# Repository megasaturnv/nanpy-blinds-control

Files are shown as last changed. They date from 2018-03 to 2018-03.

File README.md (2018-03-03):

# nanpy-blinds-control
Python program which performs actions depending on sunset and sunrise times

It controls an Arduino via the serial port with Nanpy: https://github.com/nanpy/nanpy

KiCad circuit board schematics are available in /blindsControlKiCad/





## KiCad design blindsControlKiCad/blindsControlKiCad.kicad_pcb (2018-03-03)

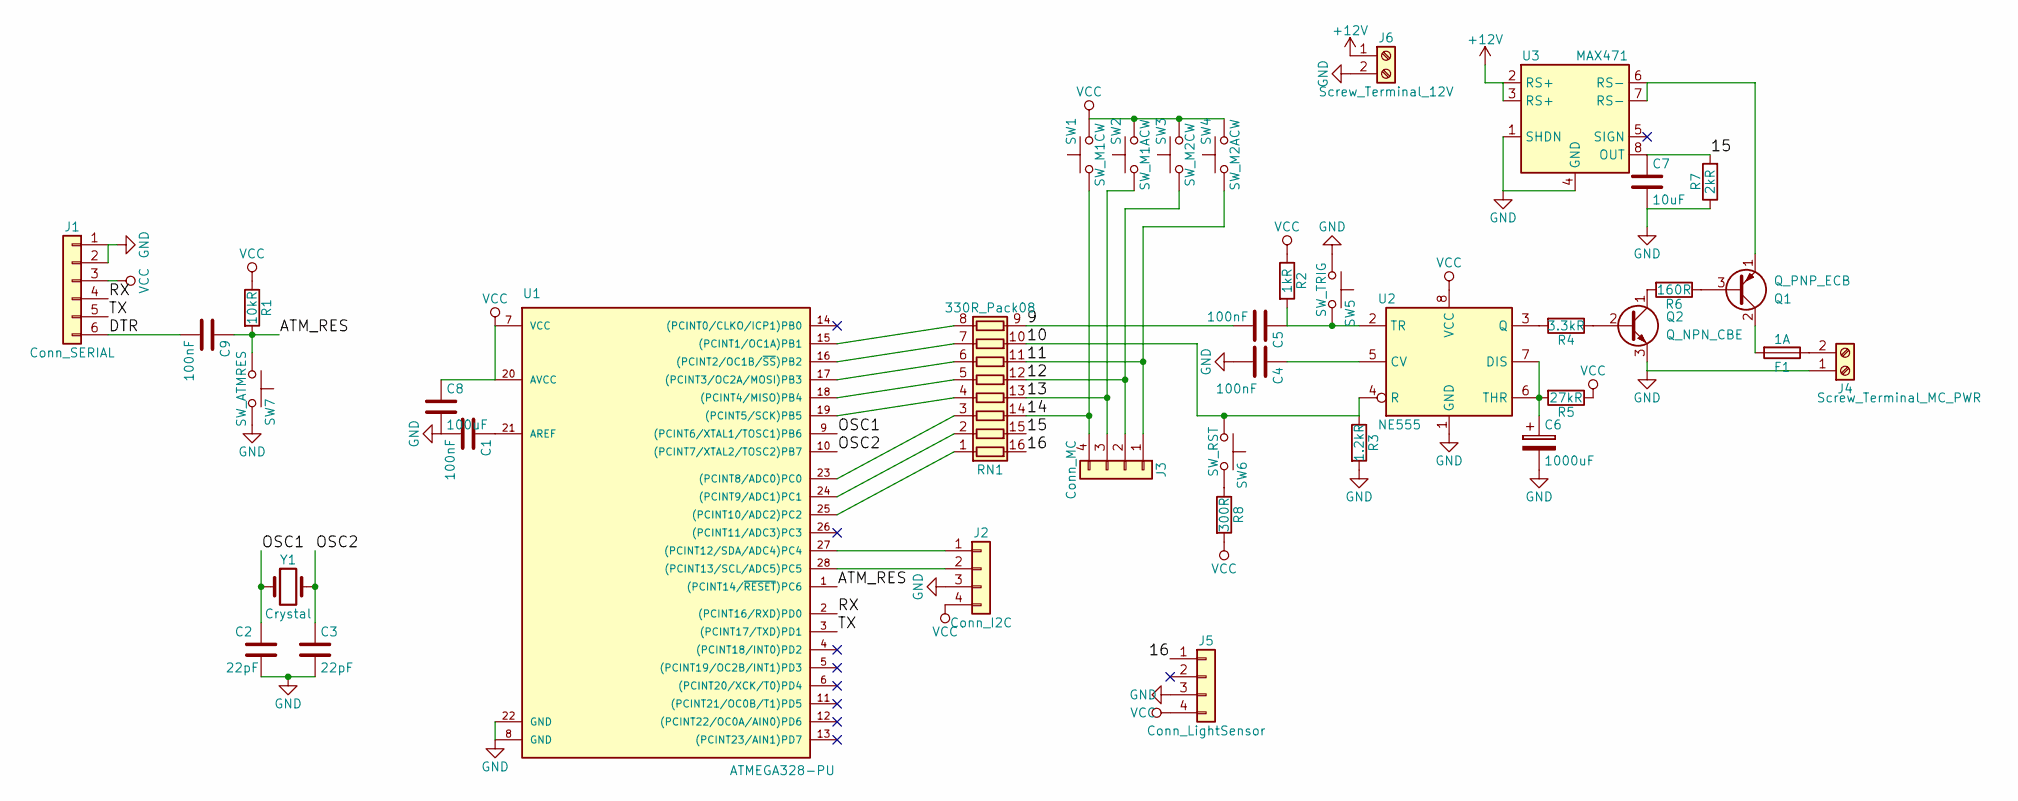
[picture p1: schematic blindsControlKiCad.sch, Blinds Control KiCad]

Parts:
C1, C4: 100nF; C_Disc_D3.0mm_W1.6mm_P2.50mm
C2, C3: 22pF; C_Disc_D3.0mm_W1.6mm_P2.50mm
C5, C9: 100nF; C_Disc_D4.3mm_W1.9mm_P5.00mm
C6: 1000uF; CP_Radial_D10.0mm_P5.00mm
C7: 10uF; CP_Radial_D5.0mm_P2.50mm
C8: 100uF; CP_Radial_D5.0mm_P2.50mm
F1: 1A; Fuseholder5x20_horiz_open_inline_Type-I
J1: Conn_SERIAL; Pin_Header_Angled_1x06_Pitch2.54mm
J2: Conn_I2C; Pin_Header_Straight_1x04_Pitch2.54mm
J3: Conn_MC; Pin_Header_Straight_1x04_Pitch2.54mm
J4: Screw_Terminal_MC_PWR; TerminalBlock_Phoenix_MKDS1.5-2pol
J5: Conn_LightSensor; Pin_Header_Straight_1x04_Pitch2.54mm
J6: Screw_Terminal_12V; TerminalBlock_Phoenix_MKDS1.5-2pol
Q1: Q_PNP_ECB; TO-126_Vertical
Q2: Q_NPN_CBE; TO-92_Inline_Wide
R1: 10kR; R_Axial_DIN0204_L3.6mm_D1.6mm_P5.08mm_Horizontal
R2: 1kR; R_Axial_DIN0207_L6.3mm_D2.5mm_P10.16mm_Horizontal
R3: 1.2kR; R_Axial_DIN0207_L6.3mm_D2.5mm_P10.16mm_Horizontal
R4: 3.3kR; R_Axial_DIN0207_L6.3mm_D2.5mm_P10.16mm_Horizontal
R5: 27kR; R_Axial_DIN0207_L6.3mm_D2.5mm_P15.24mm_Horizontal
R6: 160R; R_Axial_DIN0207_L6.3mm_D2.5mm_P10.16mm_Horizontal
R7: 2kR; R_Axial_DIN0309_L9.0mm_D3.2mm_P12.70mm_Horizontal
R8: 300R; R_Axial_DIN0309_L9.0mm_D3.2mm_P12.70mm_Horizontal
RN1: 330R_Pack08; DIP-16_W7.62mm
SW1: SW_M1CW; SW_Tactile_Straight_KSA0Axx1LFTR
SW2: SW_M1ACW; SW_Tactile_Straight_KSA0Axx1LFTR
SW3: SW_M2CW; SW_Tactile_Straight_KSA0Axx1LFTR
SW4: SW_M2ACW; SW_Tactile_Straight_KSA0Axx1LFTR
SW5: SW_TRIG; SW_Tactile_Straight_KSA0Axx1LFTR
SW6: SW_RST; SW_Tactile_Straight_KSA0Axx1LFTR
SW7: SW_ATMRES; SW_Tactile_Straight_KSA0Axx1LFTR
U1: ATMEGA328-PU; DIP-28_W7.62mm
U2: NE555; DIP-8_W7.62mm
U3: MAX471; DIP-8_W7.62mm
Y1: Crystal; Crystal_HC49-4H_Vertical

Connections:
+12V: J6.1, U3.2 (RS+), U3.3 (RS+)
/9: C5.2, RN1.9 (R8.2)
/10: R3.1, RN1.10 (R7.2), SW6.1, U2.4 (R)
/11: J3.1, RN1.11 (R6.2), SW4.1
/12: J3.2, RN1.12 (R5.2), SW3.1
/13: J3.3, RN1.13 (R4.2), SW2.1
/14: J3.4, RN1.14 (R3.2), SW1.1
/15: C7.1, R7.2, RN1.15 (R2.2), U3.8 (OUT)
/16: J5.1, RN1.16 (R1.2)
/ATM_RES: C9.1, R1.2, SW7.1, U1.1 ((PCINT14/~RESET~)PC6)
/DTR: C9.2, J1.6
/OSC1: C2.1, U1.9 ((PCINT6/XTAL1/TOSC1)PB6), Y1.1
/OSC2: C3.1, U1.10 ((PCINT7/XTAL2/TOSC2)PB7), Y1.2
/RX: J1.4, U1.2 ((PCINT16/RXD)PD0)
/TX: J1.5, U1.3 ((PCINT17/TXD)PD1)
GND: C1.2, C2.2, C3.2, C4.2, C6.2, C7.2, C8.2, J1.1, J1.2, J2.3, J4.1, J5.3, J6.2, Q2.3 (E), R3.2, R7.1, SW5.1, SW7.2, U1.8 (GND), U1.22 (GND), U2.1 (GND), U3.1 (SHDN), U3.4 (GND)
unnamed: C1.1, U1.21 (AREF)
unnamed: C4.1, U2.5 (CV)
unnamed: C5.1, R2.2, SW5.2, U2.2 (TR)
unnamed: C6.1, R5.2, U2.6 (THR), U2.7 (DIS)
unnamed: F1.1, J4.2
unnamed: F1.2, Q1.2 (C)
unnamed: J2.1, U1.27 ((PCINT12/SDA/ADC4)PC4)
unnamed: J2.2, U1.28 ((PCINT13/SCL/ADC5)PC5)
unnamed: Q1.1 (E), U3.6 (RS-), U3.7 (RS-)
unnamed: Q1.3 (B), R6.1
unnamed: Q2.1 (C), R6.2
unnamed: Q2.2 (B), R4.1
unnamed: R4.2, U2.3 (Q)
unnamed: R8.1, SW6.2
unnamed: RN1.1 (R1.1), U1.25 ((PCINT10/ADC2)PC2)
unnamed: RN1.2 (R2.1), U1.24 ((PCINT9/ADC1)PC1)
unnamed: RN1.3 (R3.1), U1.23 ((PCINT8/ADC0)PC0)
unnamed: RN1.4 (R4.1), U1.19 ((PCINT5/SCK)PB5)
unnamed: RN1.5 (R5.1), U1.18 ((PCINT4/MISO)PB4)
unnamed: RN1.6 (R6.1), U1.17 ((PCINT3/OC2A/MOSI)PB3)
unnamed: RN1.7 (R7.1), U1.16 ((PCINT2/OC1B/~SS~)PB2)
unnamed: RN1.8 (R8.1), U1.15 ((PCINT1/OC1A)PB1)
VCC: C8.1, J1.3, J2.4, J5.4, R1.1, R2.1, R5.1, R8.2, SW1.2, SW2.2, SW3.2, SW4.2, U1.7 (VCC), U1.20 (AVCC), U2.8 (VCC)

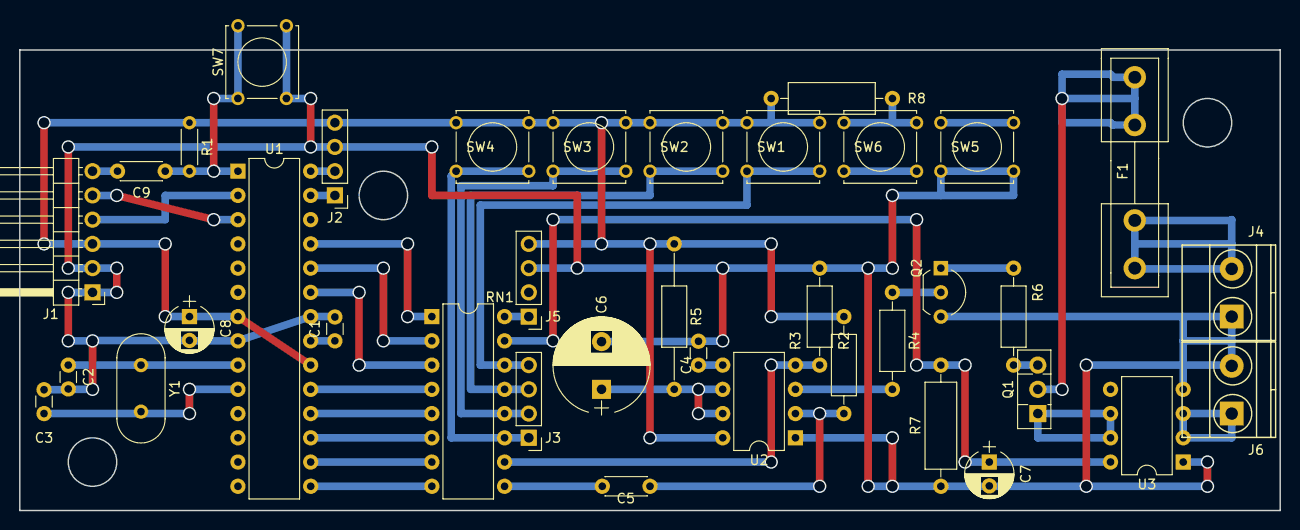
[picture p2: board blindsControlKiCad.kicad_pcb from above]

Board: 2 copper layers, 132.1 x 48.3 mm, 38 parts (0 on the bottom side), 39 nets.

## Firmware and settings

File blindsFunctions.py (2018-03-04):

#!/usr/bin/python3
#import time, nanpy, nanpy.arduinotree, re, datetime, urllib.request
import time, datetime, re, urllib.request
from html.parser import HTMLParser

DEFAULT_LOG_PATH = './log.csv'
MOTOR_CONTROLLER_POWER_PIN = 9 # Connects to a monostable 555 through a capacitor. When HIGH power will be given to the motor controller for 30 seconds via NPN transistor (consisting of an NPN transistor and a PNP power transistor), as a safety precaution incase the arduino crashes
MOTOR_CONTROLLER_POWER_RESET_PIN = 10 # When HIGH the 555 is not reset and the 555 output is allowed to go high if MOTOR_CONTROLLER_POWER_PIN is high
MOTOR_CURRENT_PIN = 15 #Input pin for current sensing the motor controller via a MAX471 ic. Note pin: 0, 8 and 14 are all A0 in nanpy. (0-7 = A0-A7, 8-13 = A0-A5, 14-22 = A0-A7)
BLINDS_UP_PIN = 14
BLINDS_DOWN_PIN = 13
LIGHT_SENSOR_PIN = 16

verbose = True
def print_v(text, newline=True):
    if verbose:
        print(datetime.datetime.now().strftime("%Y-%m-%d %H:%M:%S ") + str(text), end='', flush=True)
    if newline:
        print()

#Class originally made by FileSottile at https://gist.github.com/FiloSottile/2352407
#Modified here for python3
class IDParser(HTMLParser):
	"""Modified HTMLParser that isolates a tag with the specified id"""
	def __init__(self, id):
		self.id = id
		self.result = None
		self.started = False
		self.depth = {}
		self.html = None
		self.watch_startpos = False
		HTMLParser.__init__(self)

	def loads(self, html):
		self.html = html
		self.feed(html)
		self.close()

	def handle_starttag(self, tag, attrs):
		attrs = dict(attrs)
		if self.started:
			self.find_startpos(None)
		if 'id' in attrs and attrs['id'] == self.id:
			self.result = [tag]
			self.started = True
			self.watch_startpos = True
		if self.started:
			if not tag in self.depth: self.depth[tag] = 0
			self.depth[tag] += 1

	def handle_endtag(self, tag):
		if self.started:
			if tag in self.depth: self.depth[tag] -= 1
			if self.depth[self.result[0]] == 0:
				self.started = False
				self.result.append(self.getpos())

	def find_startpos(self, x):
		# Needed to put the start position of the result (self.result[1]) after the opening tag with the requested id
		if self.watch_startpos:
			self.watch_startpos = False
			self.result.append(self.getpos())
	handle_entityref = handle_charref = handle_data = handle_comment = \
	handle_decl = handle_pi = unknown_decl = find_startpos

	def get_result(self):
		if self.result == None: return None
		if len(self.result) != 3: return None
		lines = self.html.split('\n')
		lines = lines[self.result[1][0]-1:self.result[2][0]]
		lines[0] = lines[0][self.result[1][1]:]
		if len(lines) == 1:
 			lines[-1] = lines[-1][:self.result[2][1]-self.result[1][1]]
		lines[-1] = lines[-1][:self.result[2][1]]
		return '\n'.join(lines).strip()

def get_element_by_id(id, html):
	"""Return the content of the tag with the specified id in the passed HTML document"""
	parser = IDParser(id)
	parser.loads(html)
	return parser.get_result()

def getSunPredictions(id, eventName):
	try:
		#Valid eventNames:
		#Astronomical twilight begins
		#Nautical twilight begins
		#Astronomical twilight begins
		#Nautical twilight begins
		#Dawn - civil twilight begins
		#Sunrise:
		#Sun at its highest (transit)
		#Sunset:
		#Dusk - civil twilight ends
		#Nautical twilight ends
		#Astronomical twilight ends
		with urllib.request.urlopen('http://www.ukweathercams.co.uk/sunrise_sunset_times.php?id=' + str(id)) as response:
			html = response.read().decode('utf-8')

		#Very bad parsing of website for sun information...
		sunPredictionsTable = get_element_by_id('sun_predictions', html) #Return all content within <div id="sun_predictions">
		sunPredictionsTable = re.sub(r'<.*?>', ' ', sunPredictionsTable) #Remove all html tags
		sunPredictionsTable = re.sub(r'^\s*$\n', '', sunPredictionsTable, flags=re.MULTILINE) #Remove blank lines
		sunPredictionsTable = re.sub(r'\n^\s*$', '', sunPredictionsTable, flags=re.MULTILINE) #Remove blank lines
		sunPredictionsTable = re.sub(r'[^\S\r\n]{2,}', ' ', sunPredictionsTable) #Converts multiple spaces into one space (check: is \S correct?)
		sunPredictionsTable = re.sub(r'^ ', '', sunPredictionsTable, flags=re.MULTILINE) #Removes lines that begin with ' '
		sunPredictionsTable = re.sub(r'\n(?=\d)', '', sunPredictionsTable) #delete newline character before time if time on a line without a title

		searchResultLine = re.search(eventName + r'.*$', sunPredictionsTable, flags=re.MULTILINE).group() #Search for correct line
		searchResultTime = re.search(r'\d\d:\d\d:\d\d',searchResultLine).group() #Search for time of event
		searchResultDatetime = datetime.datetime.combine(datetime.datetime.now().date(), datetime.datetime.strptime(searchResultTime, '%H:%M:%S').time()) #Convert searchResultTime string into datetime.time, and add the current date wth datetime.combine to produce a datetime$
		print_v('Info: eventName = ' + eventName + '    searchResultDatetime = ' + str(searchResultDatetime))
		return searchResultDatetime
	except Exception as f:
		print('Error: The following exception occured  in getSunPredictions:')
		print(f)
		writeToLogFile(f)
		#return datetime.datetime(1, 1, 1, 1, 1)
	except:
		print('Error: Unknown exception in getSunPredictions!')

def writeToLogFile(text, LOG_NAME='log', LOG_PATH=DEFAULT_LOG_PATH):
	try:
		print_v('Info: Wrote to ' + LOG_NAME + ' file: ' + str(text))
		logFile = open(LOG_PATH, 'a')
		logFile.write(datetime.datetime.now().strftime('%Y-%m-%dT%H:%M:%S')+', ' + str(text) + '\n')
		logFile.close()
	except Exception as e:
		print('Error: Failed to write to ' + LOG_NAME + ' file. Text: [' + str(text) + ']')
		print('Writing to ' + LOG_NAME + ' log file failed because: ' + str(e))

def setupPins(aa):
	global MOTOR_CONTROLLER_POWER_PIN, MOTOR_CONTROLLER_POWER_RESET_PIN, BLINDS_UP_PIN, BLINDS_DOWN_PIN, MOTOR_CURRENT_PIN
	print_v('Info: Setting up pins')
	aa.pinMode(MOTOR_CONTROLLER_POWER_PIN, aa.OUTPUT)
	aa.pinMode(MOTOR_CONTROLLER_POWER_RESET_PIN, aa.OUTPUT)
	aa.pinMode(BLINDS_UP_PIN, aa.OUTPUT)
	aa.pinMode(BLINDS_DOWN_PIN, aa.OUTPUT)
	aa.pinMode(MOTOR_CURRENT_PIN, aa.INPUT)

def unsetPins(aa):
	print_v("Info: Setting all pins to input, low")
	for i in range(1,20):
		aa.digitalWrite(i, aa.LOW)
		aa.pinMode(i, aa.INPUT)
		time.sleep(0.05)

def motorControllerState(aa, state):
	if state:
		print_v('Info: Motor controller online')
		aa.digitalWrite(MOTOR_CONTROLLER_POWER_RESET_PIN, aa.HIGH)
		time.sleep(0.2)
		aa.digitalWrite(MOTOR_CONTROLLER_POWER_PIN, aa.HIGH)
		time.sleep(0.4)
		aa.digitalWrite(MOTOR_CONTROLLER_POWER_PIN, aa.LOW)
		time.sleep(0.4)
	else:
		print_v('Info: Motor controller offline')
		aa.digitalWrite(MOTOR_CONTROLLER_POWER_RESET_PIN, aa.LOW)
		aa.digitalWrite(MOTOR_CONTROLLER_POWER_PIN, aa.LOW)
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

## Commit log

2018-03-03 Initial Upload
    [blindsControlKiCad.kicad_pcb, blindsControlKiCad.sch]
2018-03-03 Uploaded SVGs of circuit board
